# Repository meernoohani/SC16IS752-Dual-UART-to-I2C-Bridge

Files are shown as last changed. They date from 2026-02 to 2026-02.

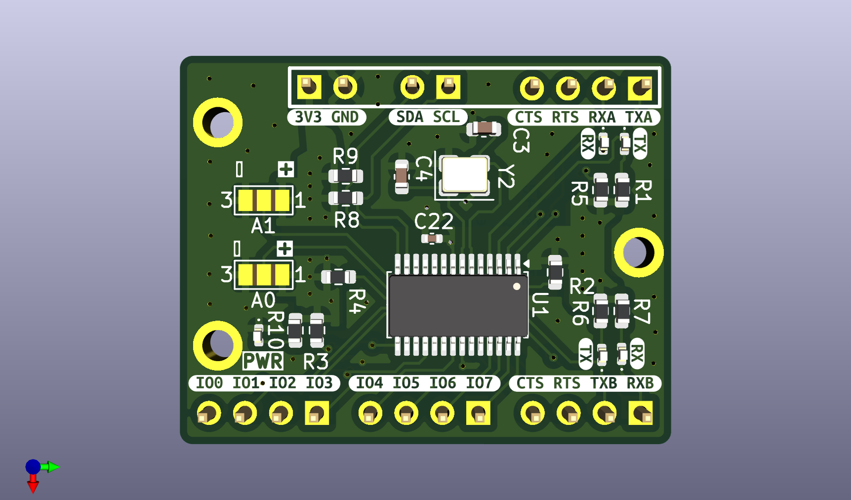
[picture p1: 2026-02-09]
Images/3D_View_front.png

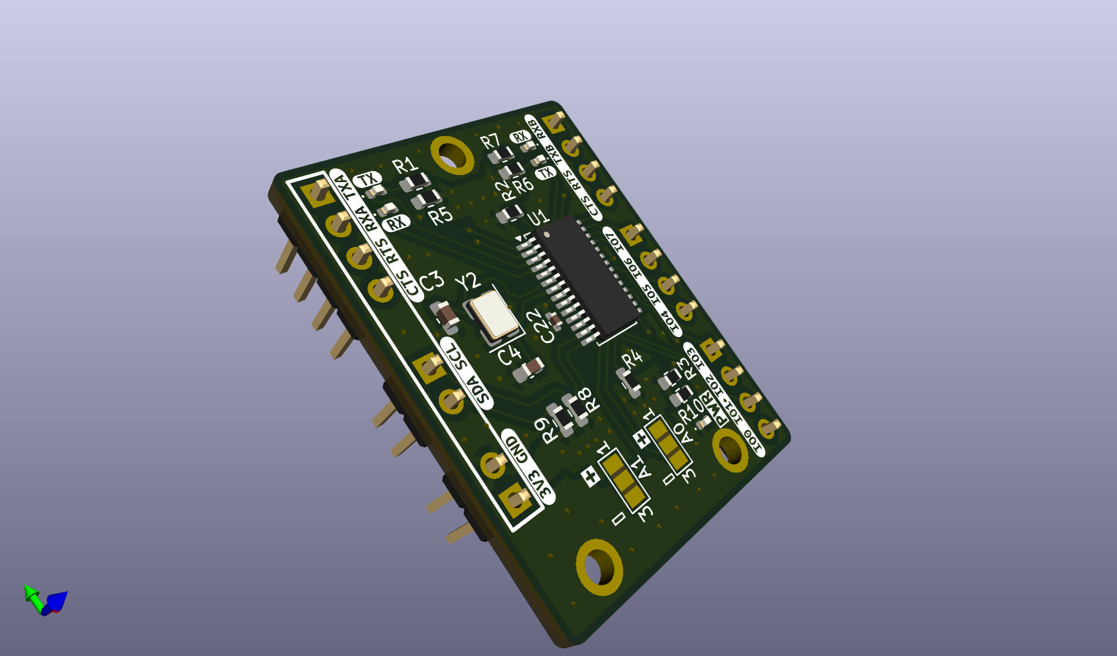
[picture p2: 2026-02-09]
Images/3D_View_front_3.png

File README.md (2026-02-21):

# SC16IS752 Dual UART to I2C Bridge

A high-performance bridge board based on the **SC16IS752**, designed to convert an I2C interface into two high-speed UART channels (up to 5 Mbps). This board is ideal for microcontrollers with limited hardware UARTS, such as when adding multiple sensors, GPS modules, or MIDI interfaces to your project. The PCB has been designed in KiCAD V.9.0 and the hardware has also been tested and verified. 

## 🛠 Features
* **Dual UART Channels:** Two independent UARTs (A and B) with 64-byte Send/Receive FIFOs.
* **I2C Interface:** Controlled via a single I2C bus, saving valuable MCU pins.
* **Onboard Crystal:** Integrated 14.7456 MHz crystal for precise baud rate generation.
* **Expanded GPIO:** Provides 8 additional programmable I/O pins (mapped to UART signals or general use).
* **Hardware Flow Control:** Full support for RTS/CTS signaling on both channels.
* **Address Selection:** Onboard jumpers (A0/A1) to easily change the I2C address.
* **Design Tool:** Created with **KiCad 9.0**.

## 📍 Pinout Overview
The board is logically organized for easy wiring:
* **Left Side:** I2C Bus (SCL/SDA), Power (3.3V/GND), and UART Channel A (TX/RX/RTS/CTS).
* **Right Side:** UART Channel B (TX/RX/RTS/CTS) and 8 General Purpose I/Os (GPIO0-GPIO7).
* **Bottom:** Address selection pads (A0, A1) and Interrupt (IRQ) output.
3D_View_front_2

## ⚙️ Hardware Specifications
| Parameter | Value |
| :--- | :--- |
| **Supply Voltage** | 3.3V DC |
| **Crystal Frequency** | 14.7456 MHz |
| **Max Baud Rate** | 5 Mbps (at 3.3V) |
| **FIFO Size** | 64 Bytes per channel |
| **I2C Speed** | Up to 400 kHz (Fast-mode) |

## 📦 Production Files
The production-ready files are optimized for **JLCPCB** manufacturing and can be found in the `/JLCPCB Production Files & BOM` folder:
* Gerber and Drill files.
* BOM (Bill of Materials) with LCSC part numbers.
* CPL (Pick-and-Place) files for SMD assembly.

---
*Note: This project is shared for reference and educational purposes.*

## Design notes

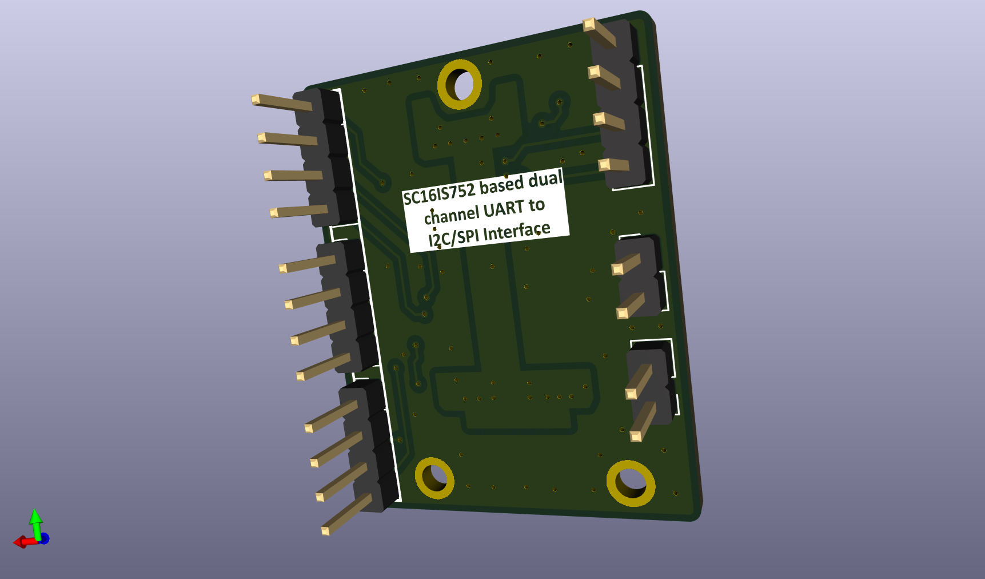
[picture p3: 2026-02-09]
Images/3D_View_back_4.png

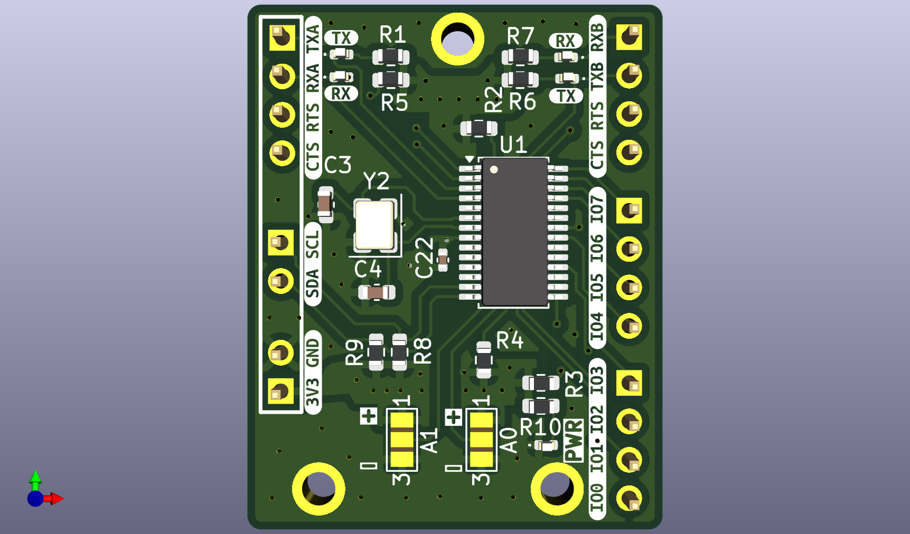
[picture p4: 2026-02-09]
Images/3D_View_front_2.png

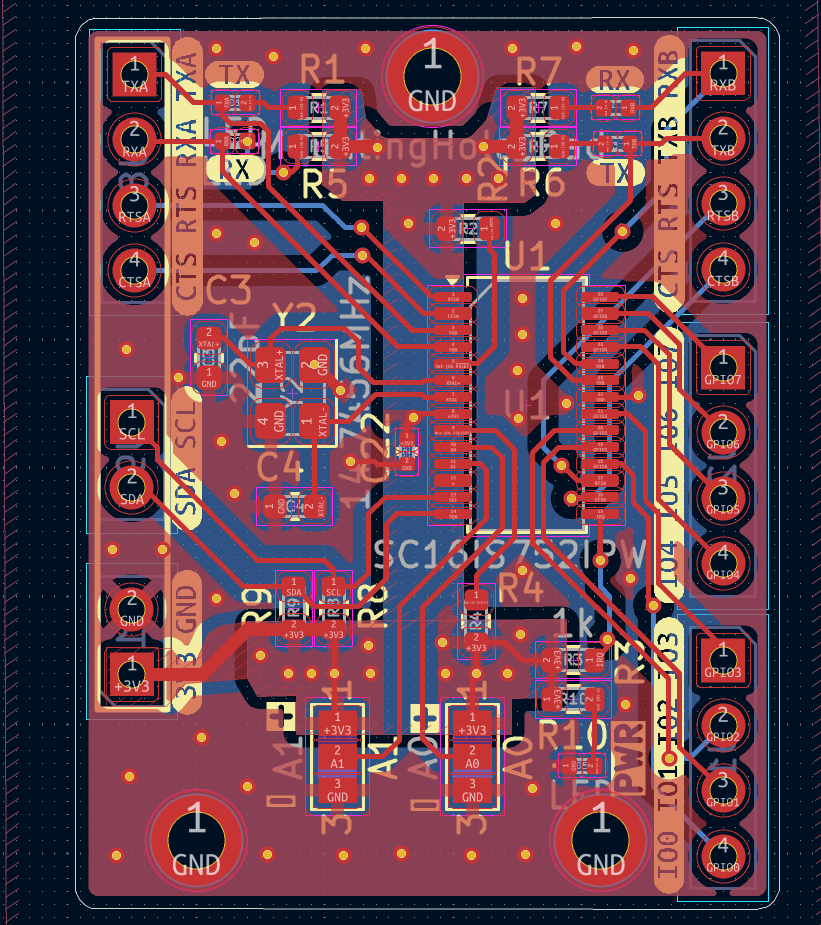
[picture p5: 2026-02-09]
Images/Layout_Front.png

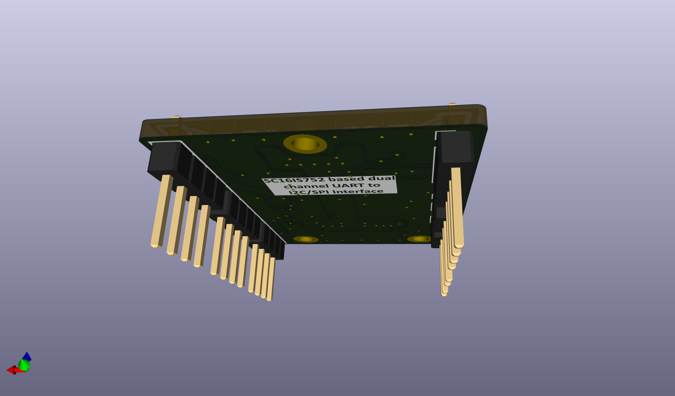
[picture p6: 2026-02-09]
Images/3D_View_front_4.png

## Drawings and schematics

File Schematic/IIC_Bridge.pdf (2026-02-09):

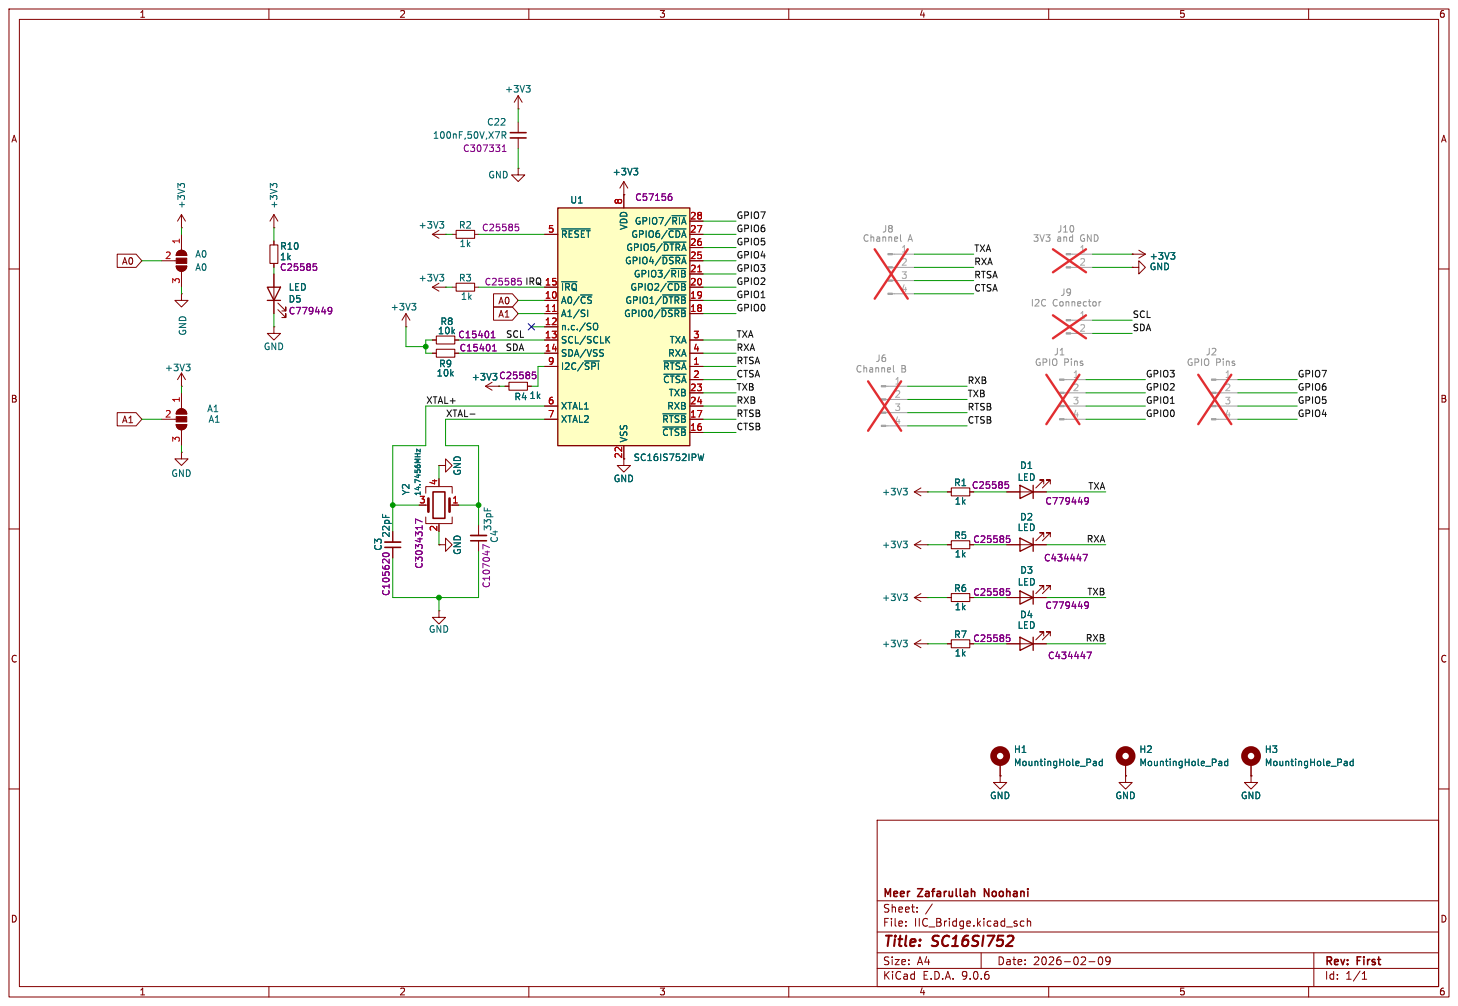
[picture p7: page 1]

SCL TXA CTSA RTSA RXA RXA RTSA
TXA GPIO0 GPIO2 GPIO1 CTSB RXB RTSB

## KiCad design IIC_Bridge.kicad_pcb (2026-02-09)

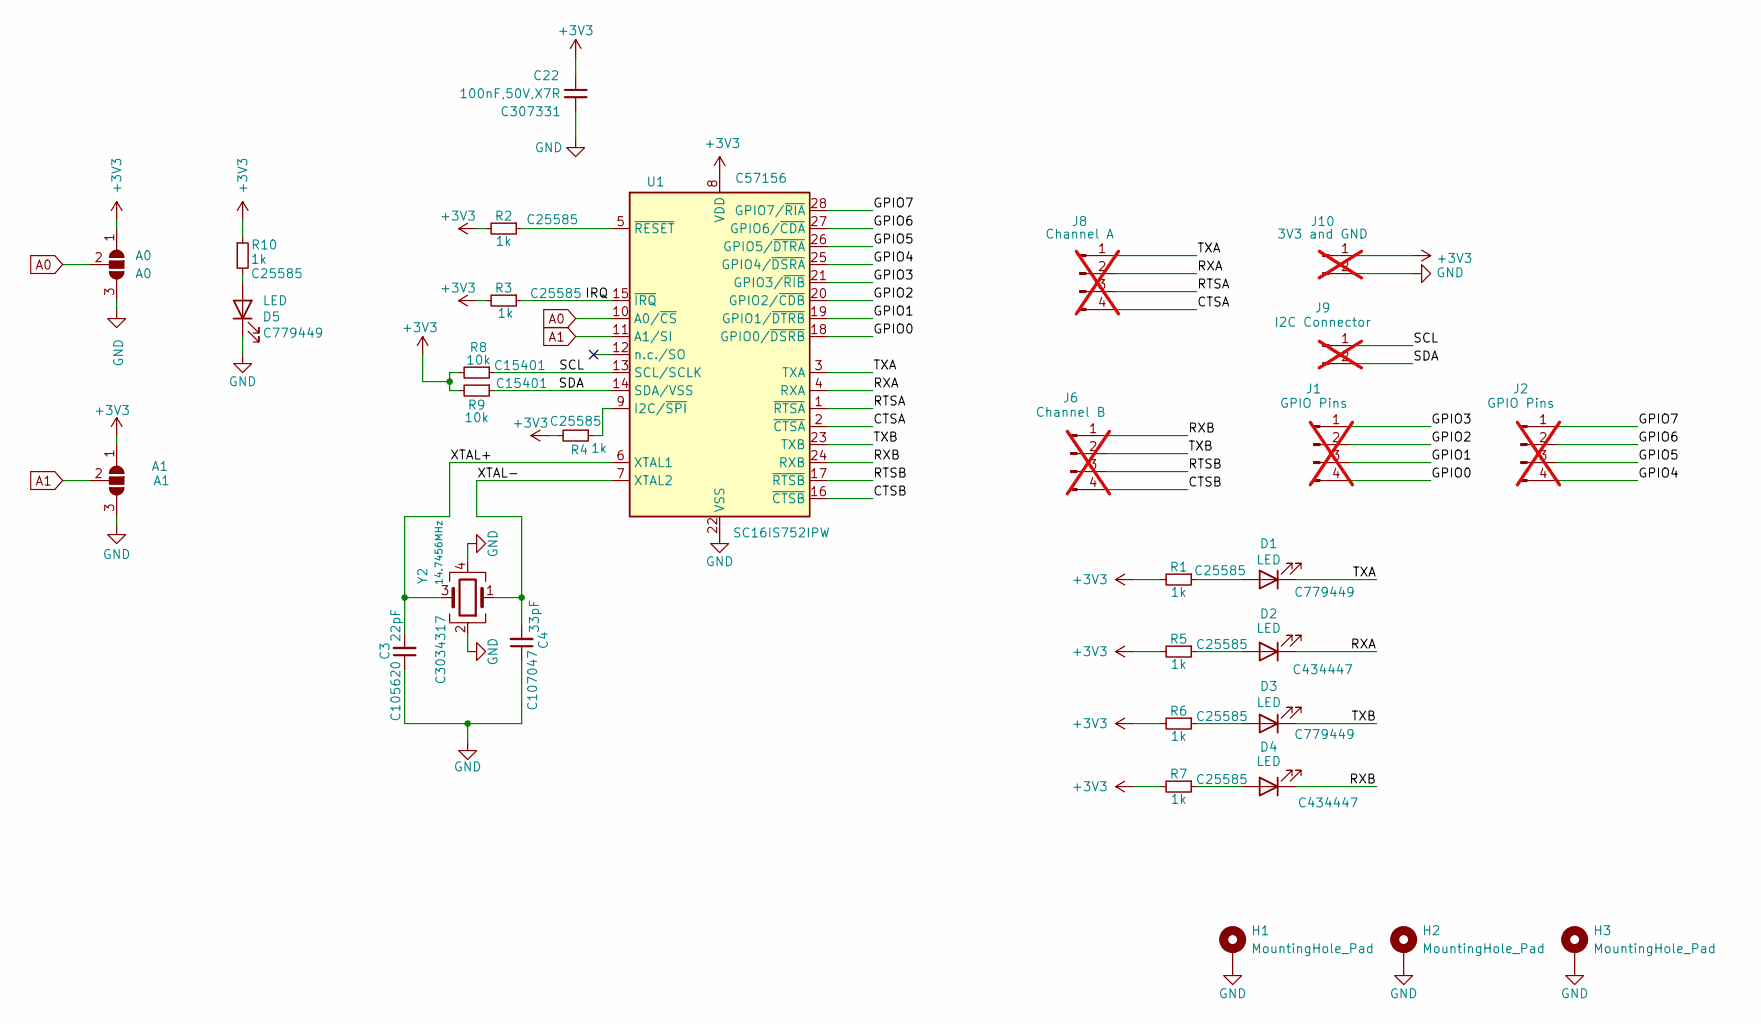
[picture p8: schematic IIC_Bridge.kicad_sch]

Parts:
A0: A0; SolderJumper-3_P1.3mm_Open_Pad1.0x1.5mm_NumberLabels
A1: A1; SolderJumper-3_P1.3mm_Open_Pad1.0x1.5mm_NumberLabels
C3: 22pF; C_0603_1608Metric; LCSC C105620
C4: 33pF; C_0603_1608Metric; LCSC C107047
C22: 100nF,50V,X7R; C_0402_1005Metric; MFGPN CL05B104KB54PNC; LCSC C307331
D1, D3, D5: LED; LED_0402_1005Metric; LCSC C779449
D2, D4: LED; LED_0402_1005Metric; LCSC C434447
H1, H2, H3: MountingHole_Pad; MountingHole_2.2mm_M2_ISO7380_Pad
J1, J2: GPIO Pins; PinHeader_1x04_P2.54mm_Vertical; not fitted
J6: Channel B; PinHeader_1x04_P2.54mm_Vertical; not fitted
J8: Channel A; PinHeader_1x04_P2.54mm_Vertical; not fitted
J9: I2C Connector; PinHeader_1x02_P2.54mm_Vertical; not fitted
J10: 3V3 and GND; PinHeader_1x02_P2.54mm_Vertical; not fitted
R1, R2, R3, R4, R5, R6, R7, R10: 1k; R_0603_1608Metric; LCSC C25585
R8, R9: 10k; R_0603_1608Metric; LCSC C15401
U1: SC16IS752IPW; TSSOP-28_4.4x9.7mm_P0.65mm; LCSC C57156
Y2: 14.7456MHz; Crystal_SMD_3225-4Pin_3.2x2.5mm; LCSC C3034317

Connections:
+3V3: A0.1 (A), A1.1 (A), C22.1, J10.1, R1.2, R2.2, R3.2, R4.2, R5.2, R6.2, R7.2, R8.2, R9.2, R10.1, U1.8 (VDD)
/CTSA: J8.4, U1.2 (~CTSA)
/CTSB: J6.4, U1.16 (~CTSB)
/GPIO0: J1.4, U1.18 (GPIO0/~DSRB)
/GPIO1: J1.3, U1.19 (GPIO1/~DTRB)
/GPIO2: J1.2, U1.20 (GPIO2/~CDB)
/GPIO3: J1.1, U1.21 (GPIO3/~RIB)
/GPIO4: J2.4, U1.25 (GPIO4/~DSRA)
/GPIO5: J2.3, U1.26 (GPIO5/~DTRA)
/GPIO6: J2.2, U1.27 (GPIO6/~CDA)
/GPIO7: J2.1, U1.28 (GPIO7/~RIA)
/IRQ: R3.1, U1.15 (~IRQ)
/RTSA: J8.3, U1.1 (~RTSA)
/RTSB: J6.3, U1.17 (~RTSB)
/RXA: D2.1 (K), J8.2, U1.4 (RXA)
/RXB: D4.1 (K), J6.1, U1.24 (RXB)
/SCL: J9.1, R8.1, U1.13 (SCL/SCLK)
/SDA: J9.2, R9.1, U1.14 (SDA/VSS)
/TXA: D1.1 (K), J8.1, U1.3 (TXA)
/TXB: D3.1 (K), J6.2, U1.23 (TXB)
/XTAL+: C3.2, U1.6 (XTAL1), Y2.3
/XTAL-: C4.2, U1.7 (XTAL2), Y2.1
A0: A0.2 (C), U1.10 (A0/~CS)
A1: A1.2 (C), U1.11 (A1/SI)
GND: A0.3 (B), A1.3 (B), C3.1, C4.1, C22.2, D5.1 (K), H1.1, H2.1, H3.1, J10.2, U1.22 (VSS), Y2.2, Y2.4
unnamed: D1.2 (A), R1.1
unnamed: D2.2 (A), R5.1
unnamed: D3.2 (A), R6.1
unnamed: D4.2 (A), R7.1
unnamed: D5.2 (A), R10.2
unnamed: R4.1, U1.9 (I2C/~SPI)
unnamed: R2.1, U1.5 (~RESET)

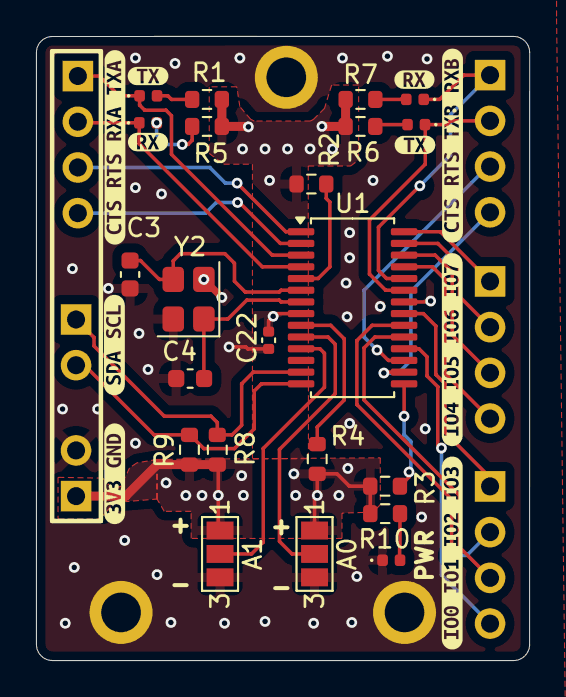
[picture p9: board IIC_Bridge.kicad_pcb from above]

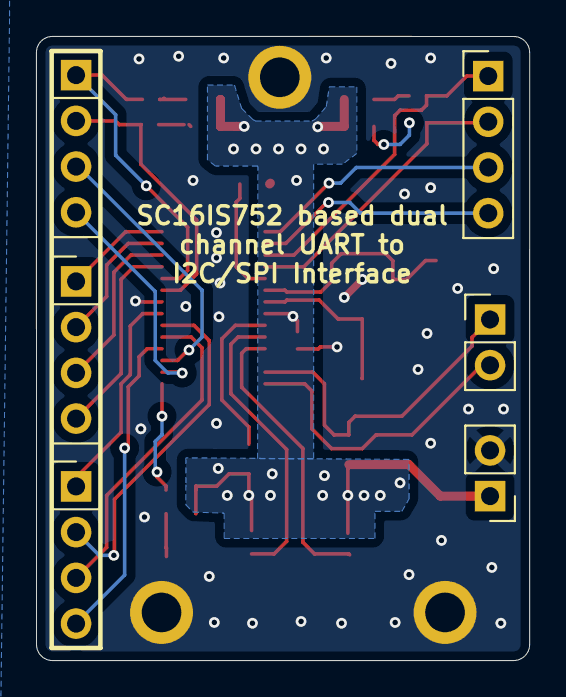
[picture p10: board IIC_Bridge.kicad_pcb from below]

Board: 2 copper layers, 27.4 x 34.7 mm, 41 parts (6 on the bottom side), 32 nets.

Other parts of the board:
kibuzzard-696A33C5: G***; kibuzzard-696A33C5
kibuzzard-696A33D3: G***; kibuzzard-696A33D3
kibuzzard-696A33E1: G***; kibuzzard-696A33E1
kibuzzard-696A37C2, kibuzzard-696A37C2#2: G***; kibuzzard-696A37C2
kibuzzard-696A37DE: G***; kibuzzard-696A37DE
kibuzzard-696A451F: G***; kibuzzard-696A451F
kibuzzard-696A3407: G***; kibuzzard-696A3407
kibuzzard-696A3458: G***; kibuzzard-696A3458
kibuzzard-696E1708: G***; kibuzzard-696E1708
